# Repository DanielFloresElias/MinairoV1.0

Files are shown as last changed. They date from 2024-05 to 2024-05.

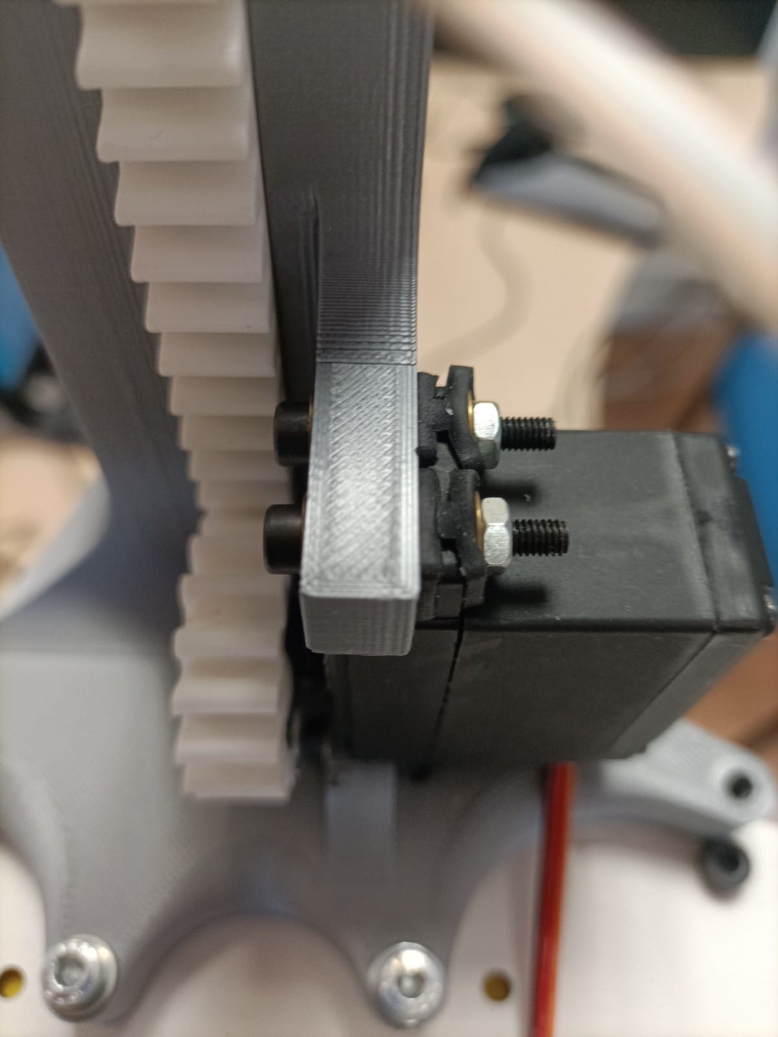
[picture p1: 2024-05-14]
Hardware/STLs/Llapis/IMG/img_pen04.jpeg

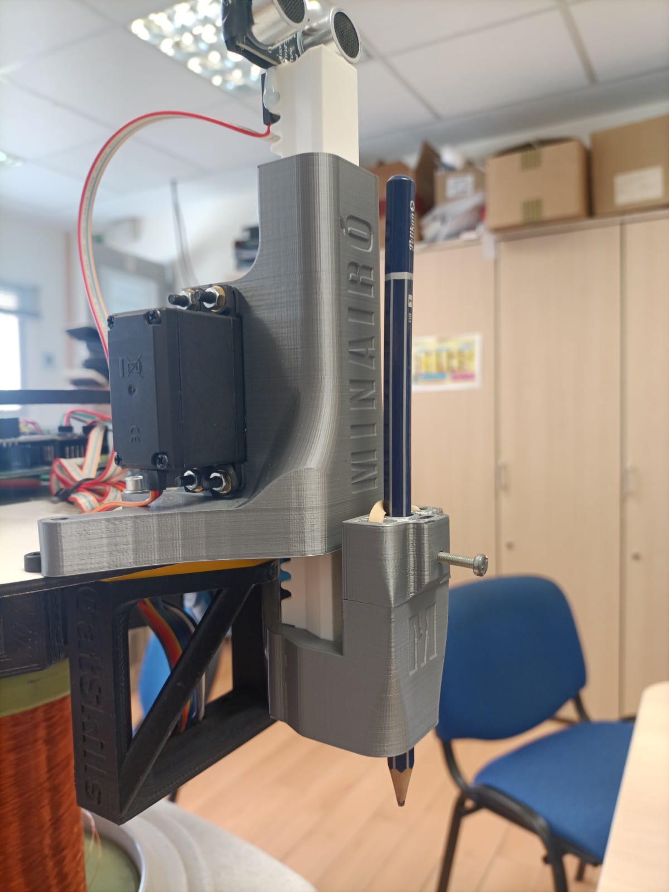
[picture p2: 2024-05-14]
Hardware/STLs/Llapis/IMG/img_pen06.jpeg

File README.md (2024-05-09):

<!--![](IMG/Minairó_Front_transp.png)-->
# MINAIRÓ V1.0 Robot
El robot Minairó es un proyecto *opensource* de robot didáctico, diseñado para aprender a programar de una manera divertida, proporcionando una plataforma *hardware* capaz de intreractuar mediante sensores y actuadores electrónicos.

Para manejar al MINAIRÓ se ha desarollado la libreria **Minairo_TCP.py**. En esta libreria encontramos los métodos necesarios para la comunicación mediante un socket TCP/IP.

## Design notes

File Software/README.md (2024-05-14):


# MINAIRÓ V1.0 Robot
El robot Minairó es un proyecto *opensource* de robot didáctico, diseñado para aprender a programar de una manera divertida, proporcionando una plataforma *hardware* capaz de intreractuar mediante sensores y actuadores electrónicos.

Para manejar al MINAIRÓ se ha desarollado la libreria **Minairo_TCP.py**. En esta libreria encontramos los métodos necesarios para la comunicación mediante un socket TCP/IP.

### Métodos para comunicaciones: [->](#item1)
```
- MinairoSocket(IP,port)
- connect():
- run():
- transmit():
- stop():
- close():
- setPullingTime(value):
- getPullingTime():
```
### Métodos para control:
```
- setVel(x,y,w):
- setX(x):
- setY(y):
- setW(w):
```
### Métodos para el seguidor de líneas:
```
- setSensorLine_Threshold(value):
- getSensorLine_Threshold():
- getSensorLine_Analog():
- getSensorLine_Digital():
```
### Método para los sensores perimetrales:
```
- getSensorSharp():
```
### Métodos para las GPIOs:
```
- confGPIO(pin,mode):
- setGPIO(pin,value):
- getGPIO():
```
### Método para entradas analógicas:
```
getAnalogs()
```
### Método para servos RC:
```
- setSERVO(pin,value):
```
### Método par SONAR:
```
- getSONAR():
```
---
---

## Métodos para comunicaciones:
### `MinairoSocket(IP,port)`
#### Descripción
Crea una instancia del Robot MINAIRÓ. En ella se incluyen todos los métodos para controlar el robot y monitorizar todos los sensores.

#### Sintaxis

```
MinairoSocket(IP,port)
```

#### Paràmetros
**IP**: Dirección IP del Robot MINAIRÓ. Por defecto 192.168.1.1.

**port**: Puerto para establecer el *socket* de comunicación. Por defecto *22*.

#### Ejemplo

```
from Minairo_TCP import *
from time import sleep

if __name__=="__main__":
    IP = '192.168.1.1'
    port = 22
    Robot = MinairoSocket(IP,port)
    Robot.run()
    Robot.setX(0.1)
    sleep(2)
    Robot.setX(0.0)
    sleep(0.5)
    Robot.close()
```
---
### `run()`
#### Descripción
El método *run()*, se conecta mediante el *socket* TCP/IP con el robot, e inicia la comunicación bidireccional ciclica entre el robot y su instancia de python.
El periodo de *polling* se establece mediante el método: *setPullingTime(value)* por defecto 25ms.

#### Sintaxis

```
run()
```

#### Paràmetros
Sin parámetros.

#### Ejemplo

```
from Minairo_TCP import *
from time import sleep

if __name__=="__main__":
    IP = '192.168.1.1'
    port = 22
    Robot = MinairoSocket(IP,port)
    Robot.run()
    Robot.setX(0.1)
    sleep(2)
    Robot.stop()
```
---
### `transmit()`
#### Descripción
El método *transmit()*, realiza una única comunicación bidireccional entre el robot y su instancia de python.En primer lugar transfiere el *OutBuffer* con todos los datos en *RAW* de control al MINAIRÓ, y seguidamente recibe el *InBuffer* con todos los datos en *RAW* procedentes de los sensores.

#### Sintaxis

```
transmit()
```

#### Paràmetros
Sin parámetros.

#### Ejemplo

```
from Minairo_TCP import *
from time import sleep

if __name__=="__main__":
    IP = '192.168.1.1'
    port = 22
    Robot = MinairoSocket(IP,port)
    Robot.connect()
    Robot.setX(0.1)
    Robot.transmit()
    sleep(2)
    Robot.setX(0.0)
    Robot.transmit()
    Robot.close()
```

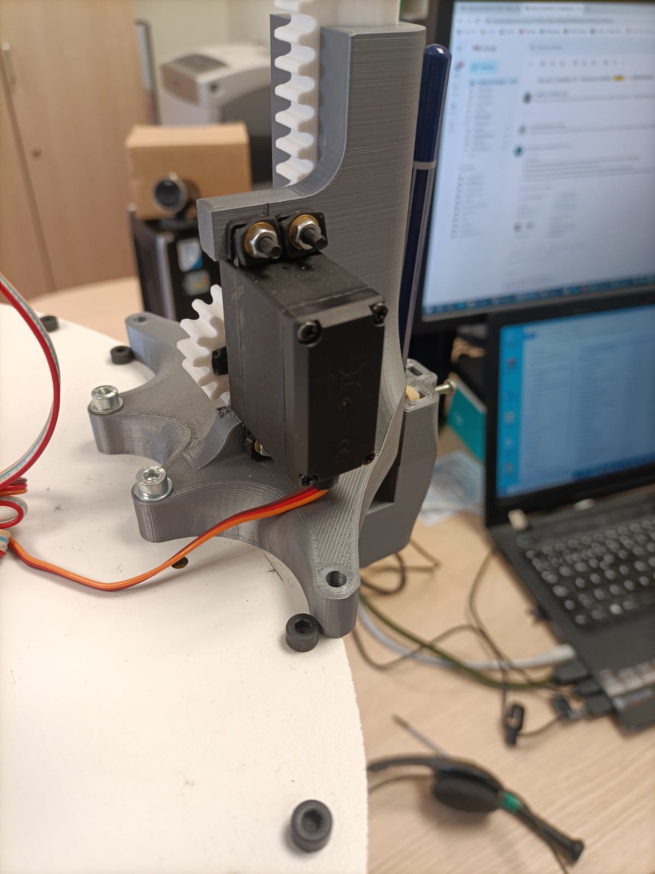
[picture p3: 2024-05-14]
Hardware/STLs/Llapis/IMG/img_pen05.jpeg

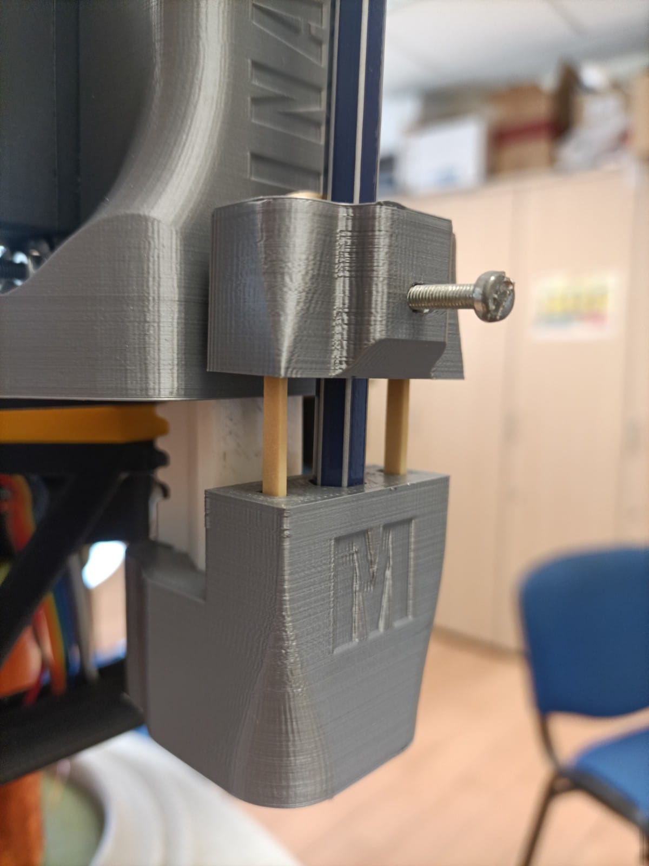
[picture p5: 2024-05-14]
Hardware/STLs/Llapis/IMG/img_pen02.jpeg

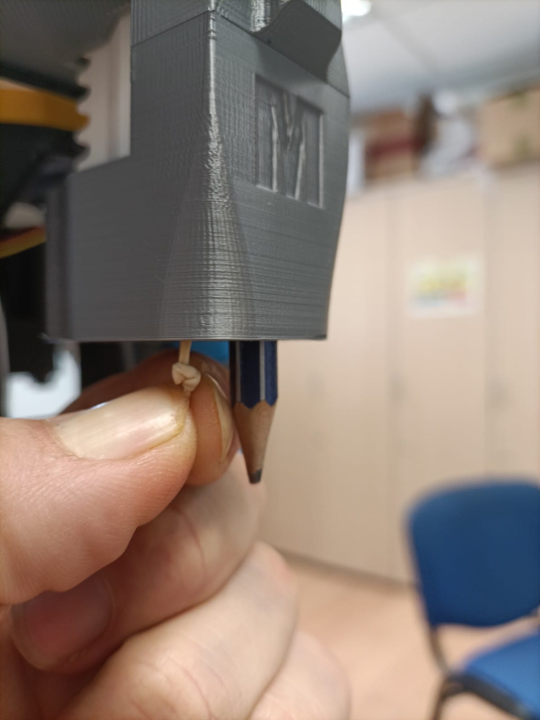
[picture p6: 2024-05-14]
Hardware/STLs/Llapis/IMG/img_pen01.jpeg

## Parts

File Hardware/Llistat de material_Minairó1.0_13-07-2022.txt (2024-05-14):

					        █╗
					       █╔╝
					       ╚╝
███╗   ███╗██╗███╗   ██╗ █████╗ ██╗██████╗  ██████╗      ██╗    ██████╗ 
████╗ ████║██║████╗  ██║██╔══██╗██║██╔══██╗██╔═══██╗    ███║   ██╔═████╗
██╔████╔██║██║██╔██╗ ██║███████║██║██████╔╝██║   ██║    ╚██║   ██║██╔██║
██║╚██╔╝██║██║██║╚██╗██║██╔══██║██║██╔══██╗██║   ██║     ██║   ████╔╝██║
██║ ╚═╝ ██║██║██║ ╚████║██║  ██║██║██║  ██║╚██████╔╝     ██║██╗╚██████╔╝
╚═╝     ╚═╝╚═╝╚═╝  ╚═══╝╚═╝  ╚═╝╚═╝╚═╝  ╚═╝ ╚═════╝      ╚═╝╚═╝ ╚═════╝ 
        __  ___   ___      ___                          ___               __        ___ ___                         __  
| |\ | /__`  |  |  |  |  |  |        |  /\  |  |  |\/| |__     |__| |  | / _` |  | |__   |     \  /  /\  |    |    /__` 
| | \| .__/  |  |  |  \__/  |     \__/ /~~\ \__/  |  | |___    |  | \__/ \__> \__/ |___  |      \/  /~~\ |___ |___ .__/ 
                                                                                                                                                                                              

1x Roda ominidreccional:
	Impressió PLA:
		- 2x "BaseRoda80mm.stl"
		- 2x "BaseRoda80mm_B.stl"
	Impressió TPU:
		- 6x "Rodillo80mm_coixinet11mm.stl"
	Ferreteria:
		- 12x Tornillo Hallen M3 16mm
		- 9x Tuerca M3
		- 6x Barilla roscada M5 49mm
		- 12x Arandela M5
		- 12x cojinete MR115-2RS (11x5x4)
		- 1x  eje 6 mm / M3 de Pololu 1999 (https://www.pololu.com/product/1999)
Electrico:
	MUCHOS DE ESTOS COMPONENTES SE PUEDEN ADQUIRIR EN WWW.BRICOGEEK.COM
	- 3x Motor:  Motor con reductora 70:1 con encoder de Pololu 4754 (https://www.pololu.com/product/4754)
	- 2x Driver Motor: Dual VNH5019 Motor Driver Shield for Arduino (https://www.pololu.com/product/2507)
	- 3x Arduino Nano Every de Arduino ABX00028
	- 1x Regulador DC-DC 12-24V a 5V (5A) de BricoGeek (https://tienda.bricogeek.com/convertidores-de-voltaje/1650-regulador-dc-dc-12-24v-a-5v-5a.html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)
	- 1x Conector XT60 batería.
	- 2x Bateria tipo CONGA 14,4V Li-Ion
	- 4x Sensor de distancia 2-15cm - Sharp GP2Y0A51SK0F de Pololu 2450 (2-150mm) / Sensor de proximidad Sharp GP2Y0A21YK de Pololu 136 (100-800mm)
	- 1x Array de sensores infrarrojos QTR-8RC (Digital) (https://www.pololu.com/product/961)
	- 1x ESP32 Wroom WIFI + Bluetooth (https://tienda.bricogeek.com/arduino-compatibles/1274-esp32-wroom-wifi-bluetooth.html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)
	- 1x 4 Channel IIC I2C Logic Level Converter Bi-Directional Module 5V to 3.3V For Arduino (https://www.amazon.es/dp/B06Y5KKMLL?psc=1&ref=ppx_yo2ov_dt_b_product_details)

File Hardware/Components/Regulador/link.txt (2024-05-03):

https://tienda.bricogeek.com/convertidores-de-voltaje/1650-regulador-dc-dc-12-24v-a-5v-5a.html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

Características:

Voltaje de entrada: 12 a 24V
Voltaje de salida: 5V
Corriente de salida: 5A max
Eficiencia: 90%
Ripple: 150mA (p-p)
Corriente sin carga: 15mA
Protección con sobre corriente y sobre voltaje.
Dimensiones: 63x32x18mm
Peso: 65 gramos

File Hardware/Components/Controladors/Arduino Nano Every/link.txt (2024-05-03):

https://docs.arduino.cc/hardware/nano-every

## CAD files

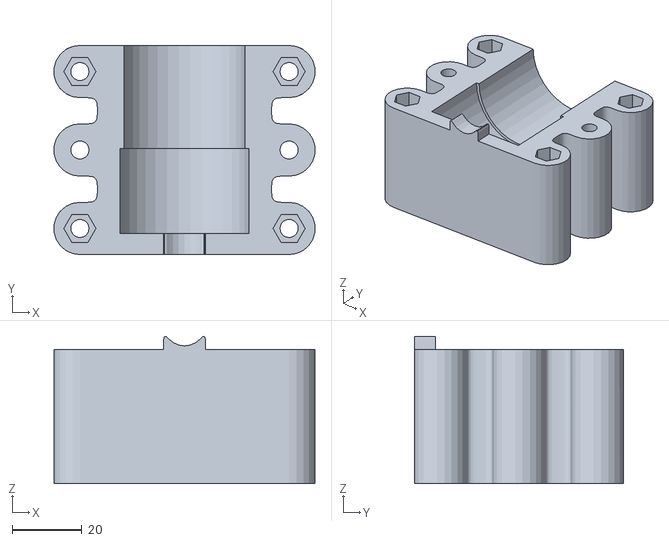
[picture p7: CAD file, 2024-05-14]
Hardware/STLs/Base_Robot/Suport_B.stl
74.8 x 60.0 x 42.2

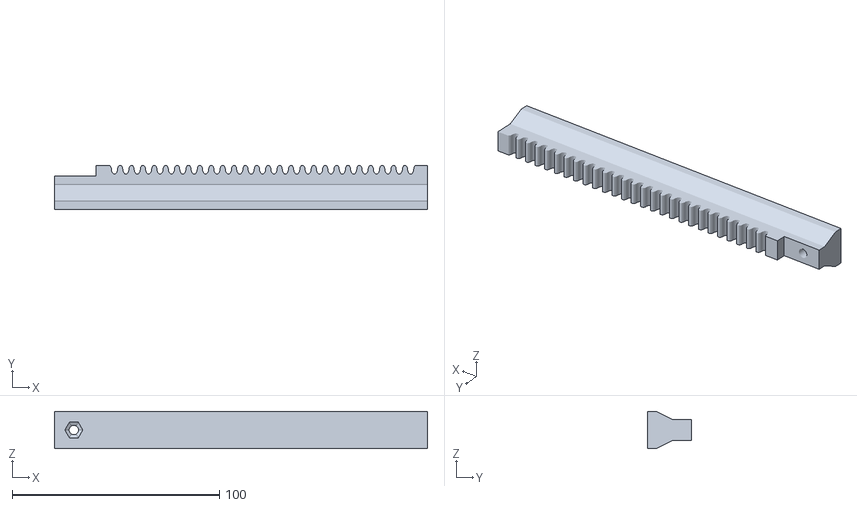
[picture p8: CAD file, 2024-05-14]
Hardware/STLs/Llapis/Corredera.STL
180.0 x 21.0 x 18.0

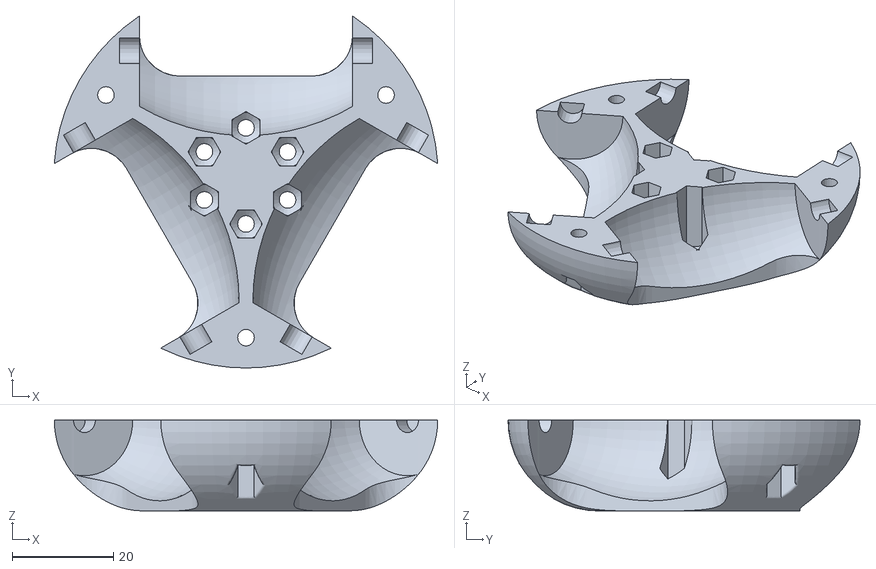
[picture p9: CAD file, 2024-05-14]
Hardware/STLs/Rodes/BaseRoda80mm_B.stl
75.8 x 69.6 x 18.0

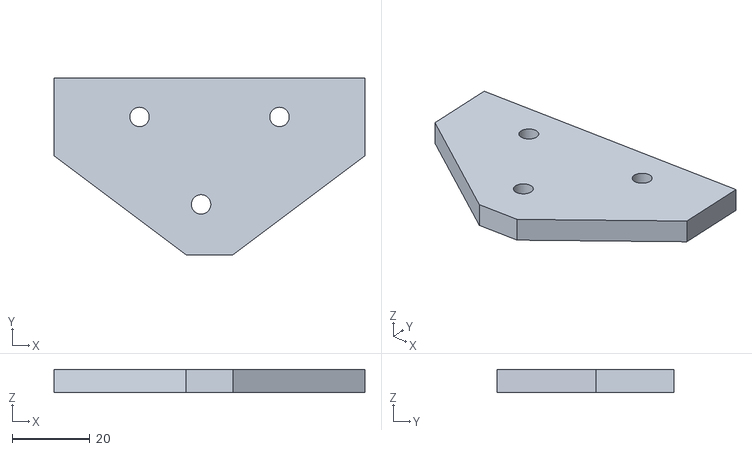
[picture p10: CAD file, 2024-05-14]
Hardware/STLs/Suport Sensors/SuportSensorArray_GAP.STL
80.0 x 45.5 x 6.00

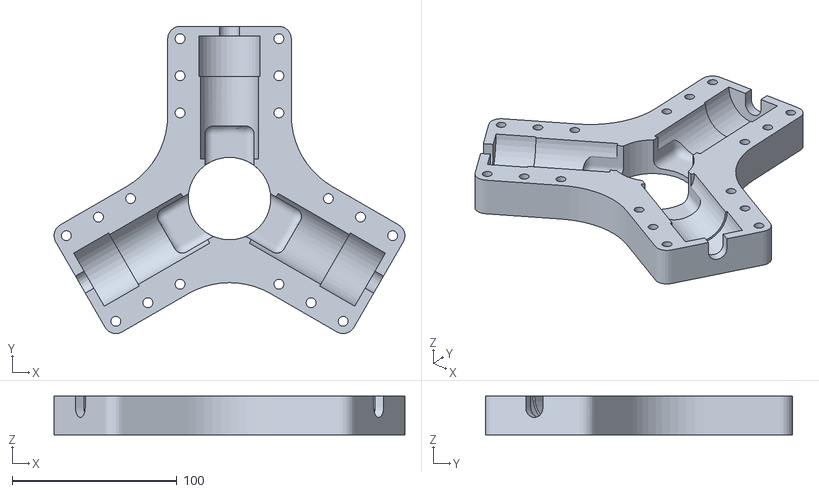
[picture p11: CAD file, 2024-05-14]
Hardware/STLs/Base_Robot/BaseRobot_BottomSide_V2.stl
212.9 x 186.4 x 23.5

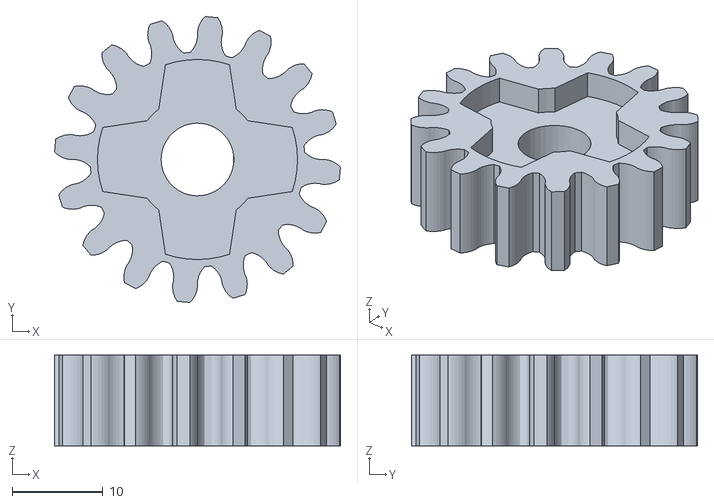
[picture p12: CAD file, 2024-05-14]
Hardware/STLs/Llapis/Engranatge.STL
31.5 x 31.5 x 10.0

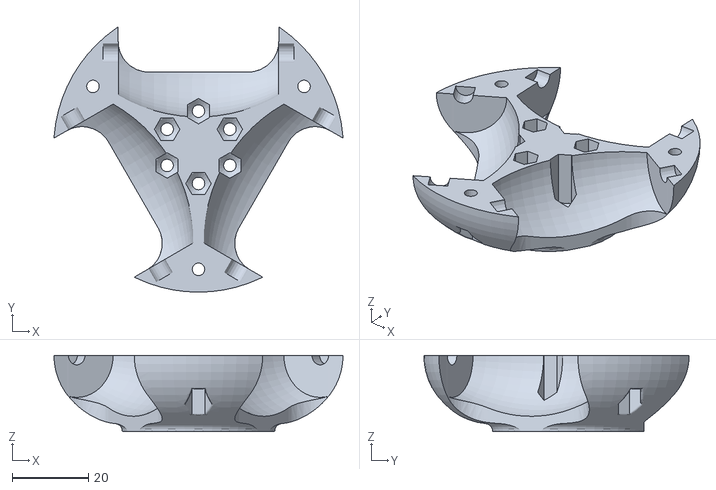
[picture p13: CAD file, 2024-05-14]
Hardware/STLs/Rodes/BaseRoda80mm.stl
75.8 x 69.6 x 20.0

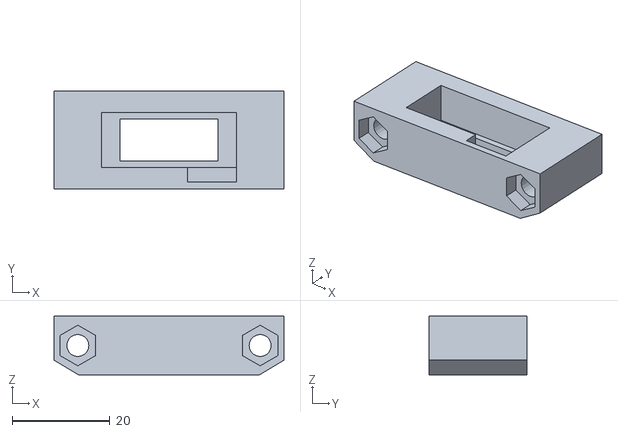
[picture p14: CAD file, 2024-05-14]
Hardware/STLs/Suport Sensors/SuportSensorOptic.stl
47.0 x 20.0 x 12.0

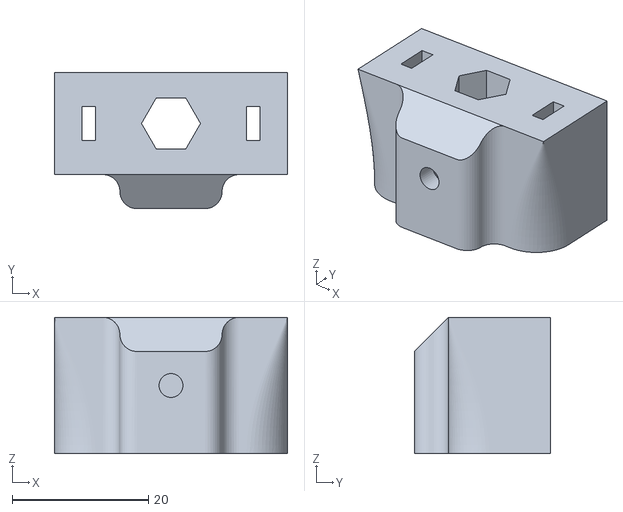
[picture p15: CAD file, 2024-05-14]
Hardware/STLs/Llapis/SuportLlapisB.STL
34.2 x 20.0 x 20.0

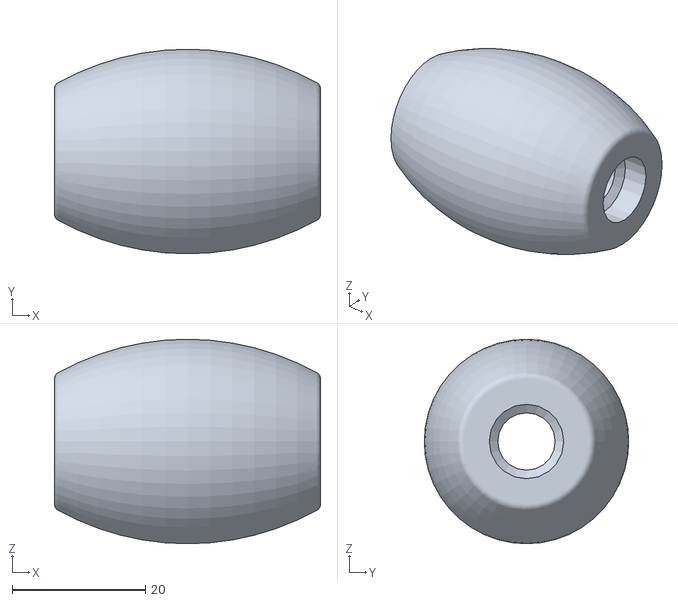
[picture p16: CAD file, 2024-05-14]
Hardware/STLs/Rodes/Rodillo80mm_coixinet11mm.stl
40.0 x 30.8 x 30.8

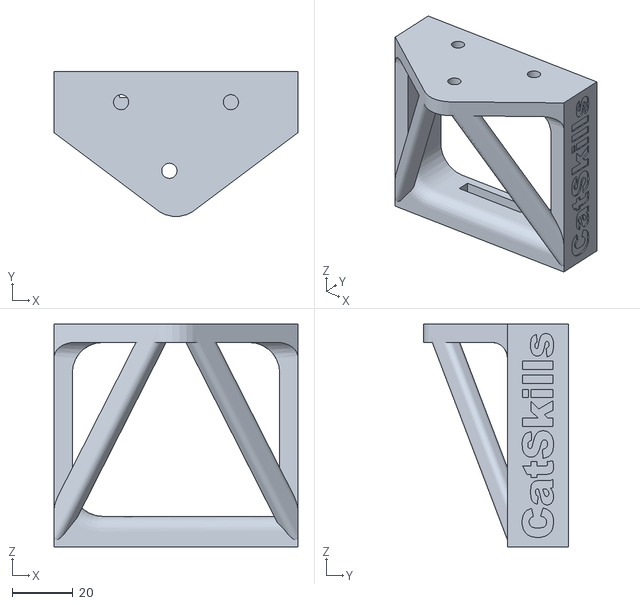
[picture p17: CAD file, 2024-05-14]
Hardware/STLs/Suport Sensors/SuportSensorArray.stl
80.0 x 47.4 x 73.0

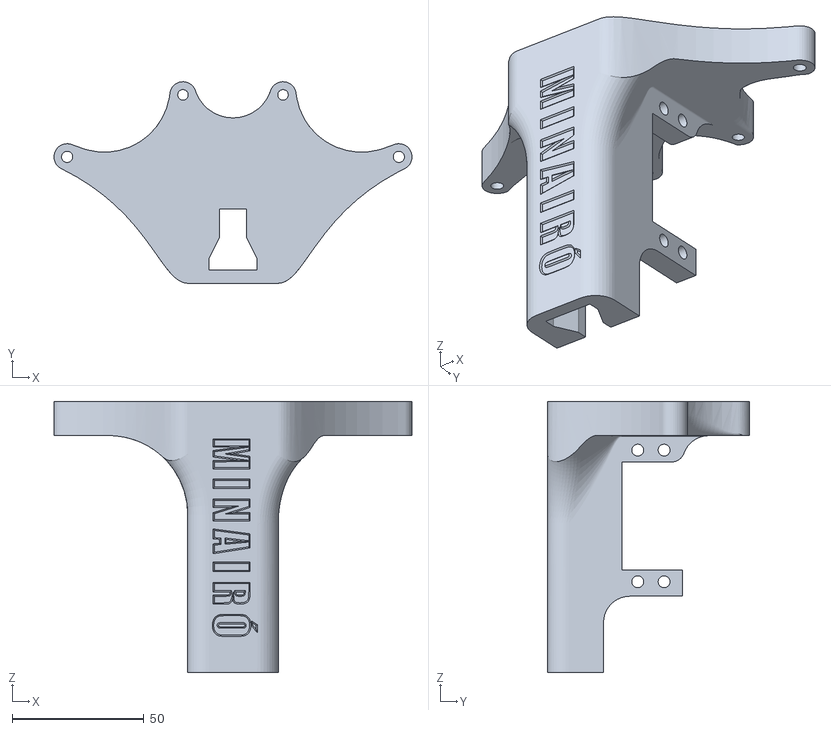
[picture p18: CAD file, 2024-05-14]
Hardware/STLs/Llapis/BaseCorredera.STL
136.0 x 76.6 x 103.0

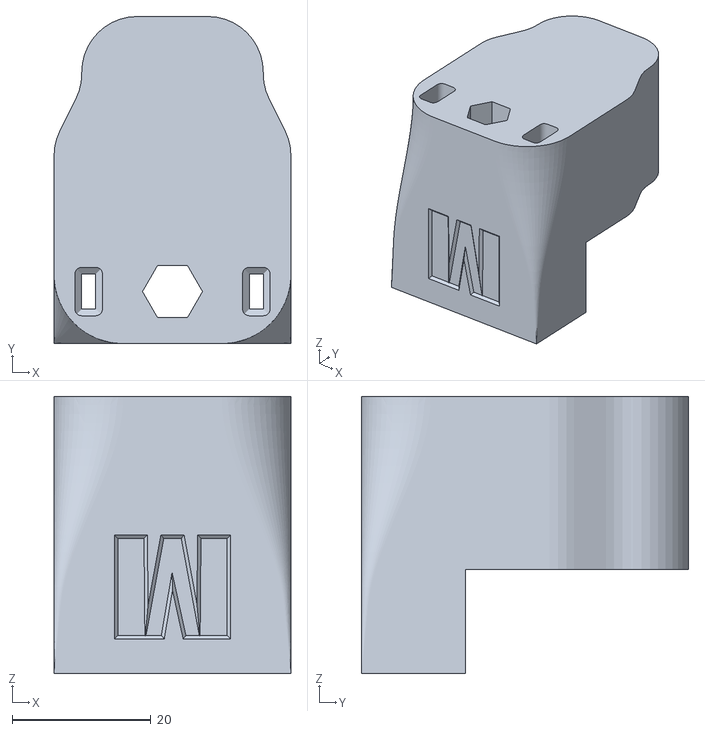
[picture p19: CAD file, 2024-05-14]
Hardware/STLs/Llapis/SuportLlapis.STL
34.2 x 47.2 x 40.0

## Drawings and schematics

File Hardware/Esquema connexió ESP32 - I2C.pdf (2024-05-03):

## MASTER

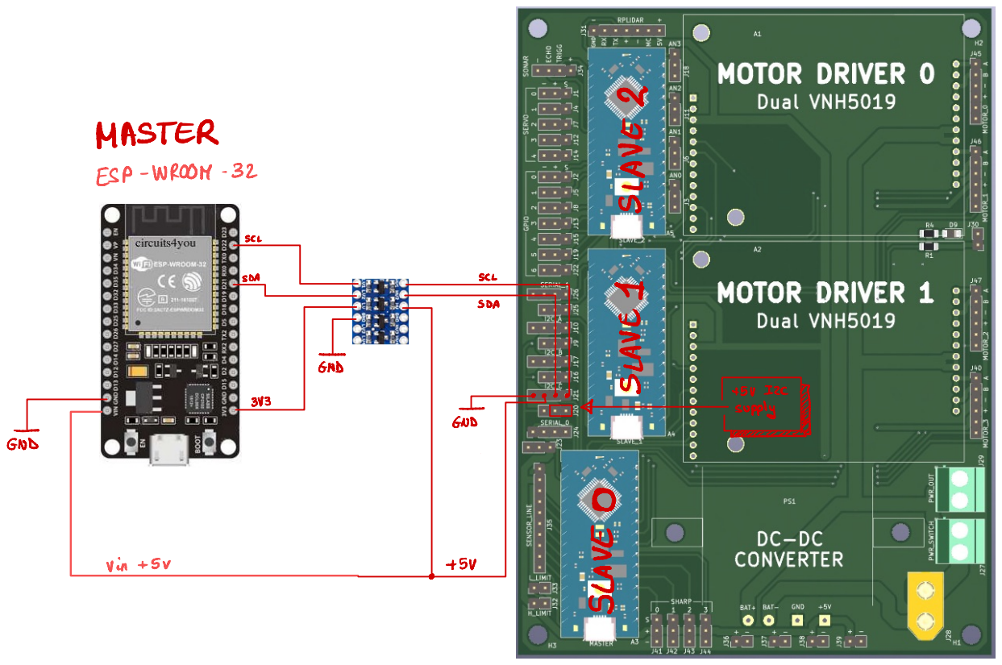
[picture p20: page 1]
ESP-WROOM-32; SDA; SCL; - SCL; goopacT; GND; vin + sv

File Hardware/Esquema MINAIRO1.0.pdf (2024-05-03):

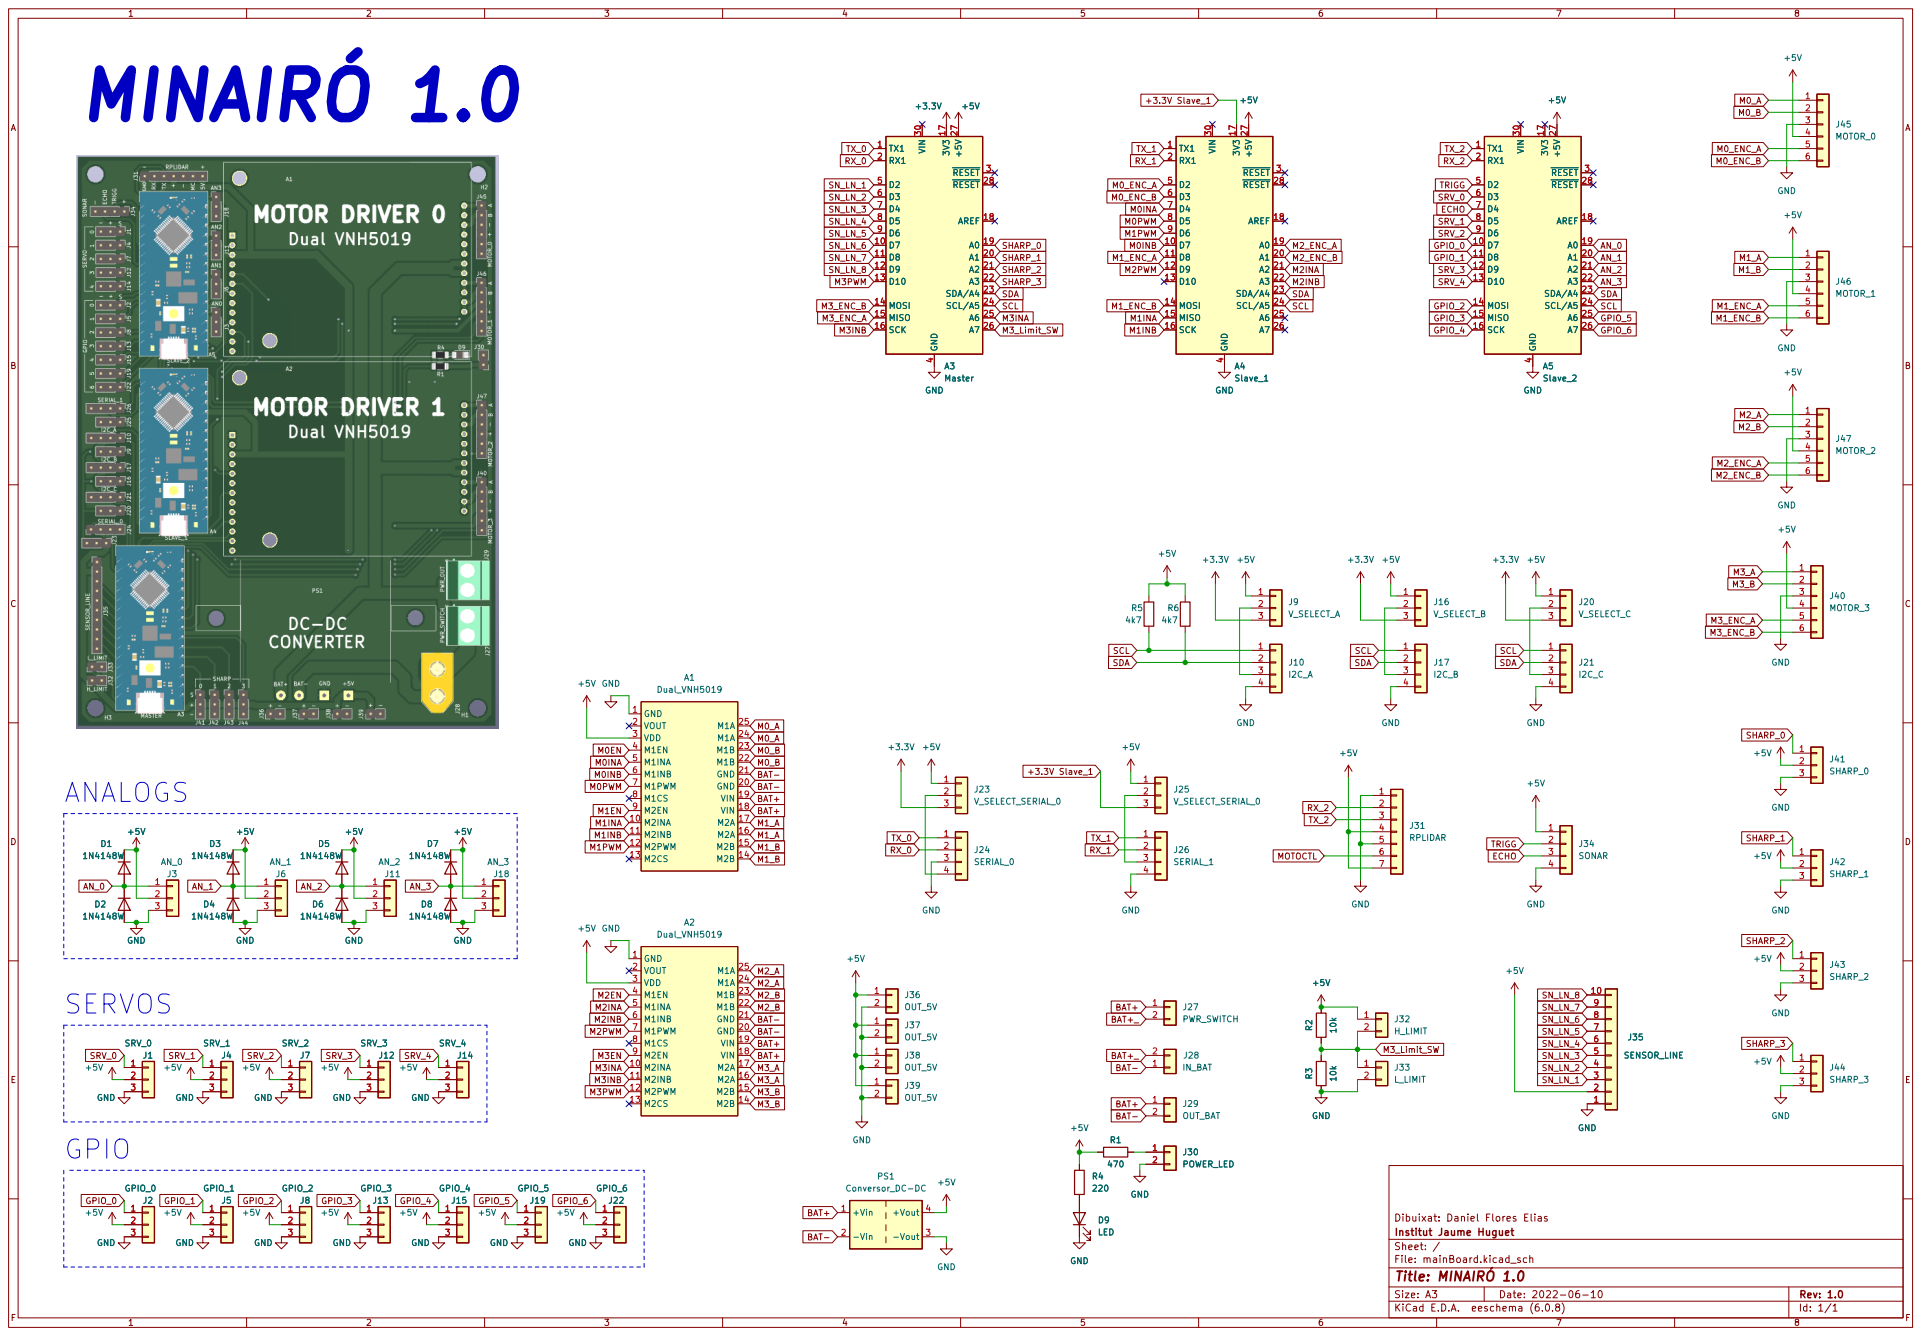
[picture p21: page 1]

Institut Jaume Huguet Dibuixat: Daniel Flores Elias GND

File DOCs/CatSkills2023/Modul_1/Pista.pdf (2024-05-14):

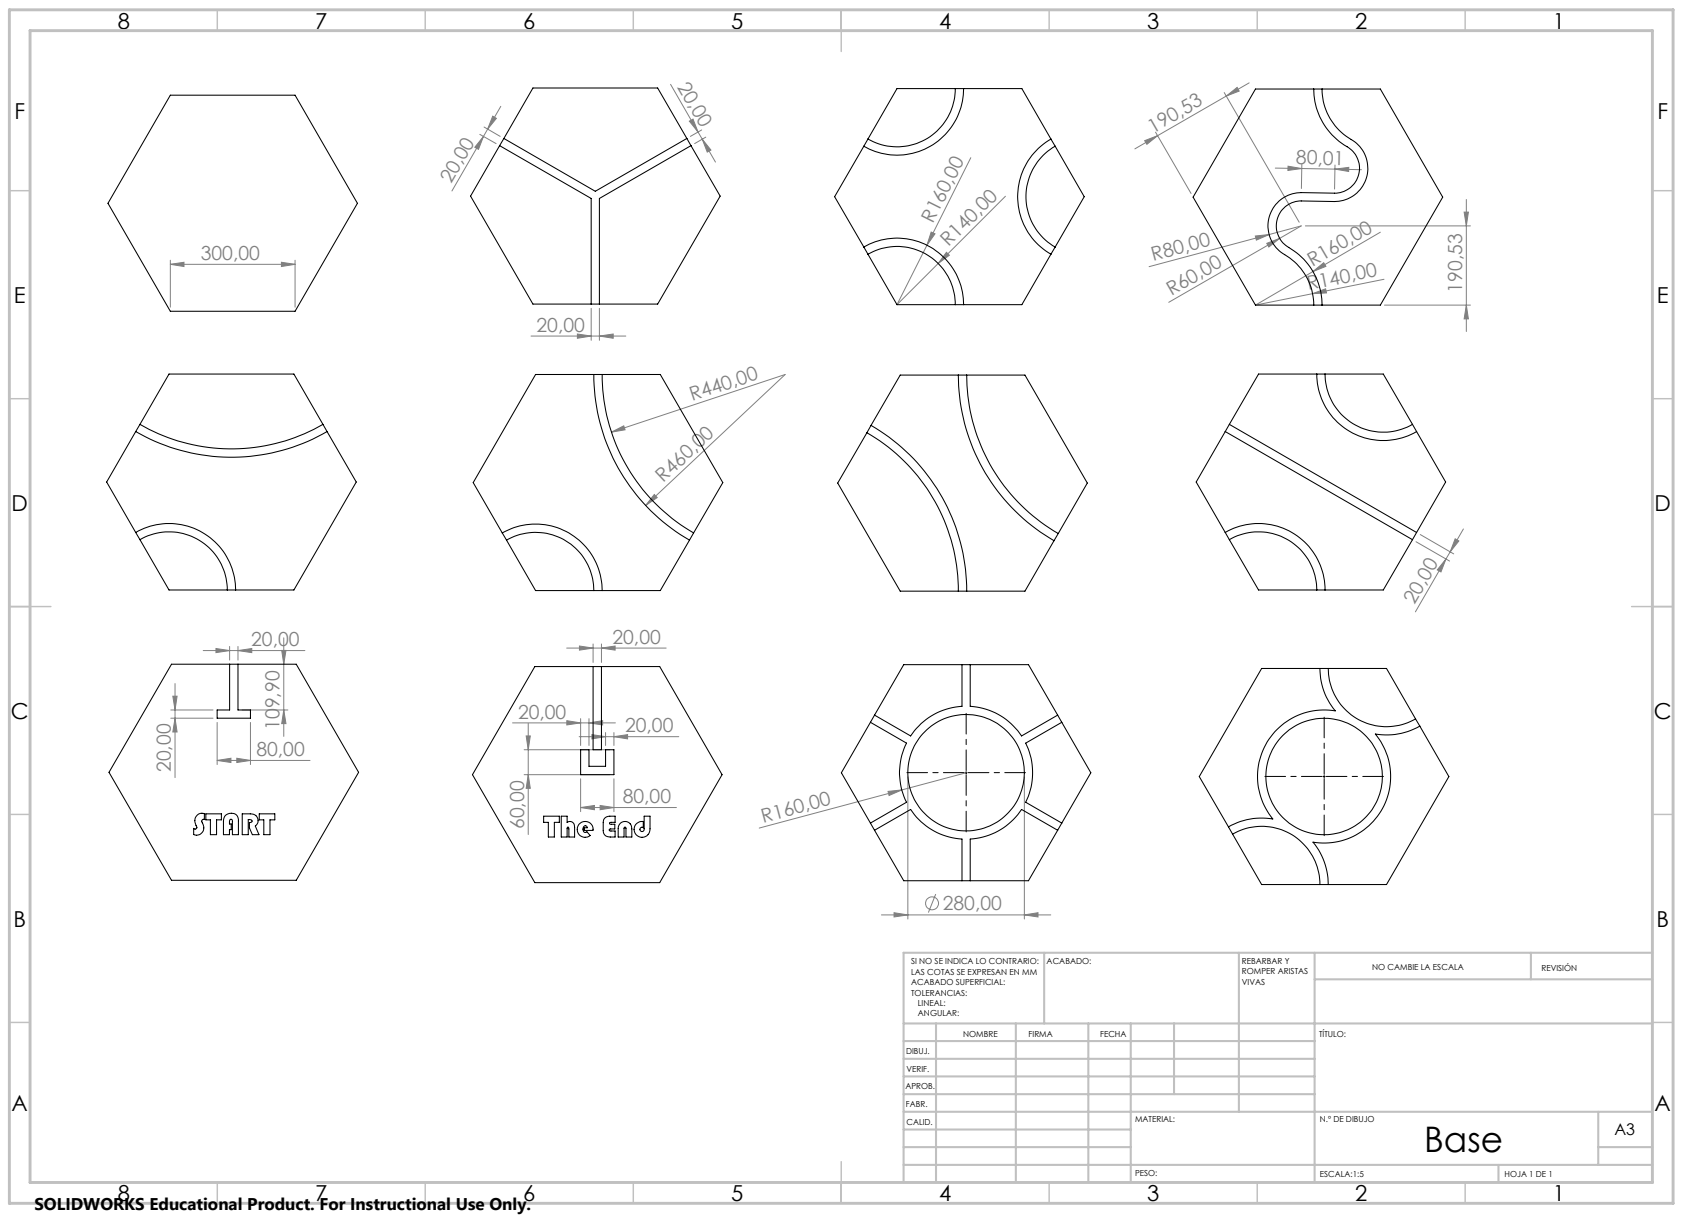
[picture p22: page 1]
ACABADO:; REBARBAR Y; ROMPER ARISTAS; NO CAMBIE LA ESCALA; REVISIÓN; ESCALA:1:5; HOJA 1 DE 1

SI NO SE INDICA LO CONTRARIO:
LAS COTAS SE EXPRESAN EN MM
ACABADO SUPERFICIAL:
TOLERANCIAS:
LINEAL:
ANGULAR:

NOMBRE | FIRMA | FECHA | | | | TÍTULO:

DIBUJ.
VERIF.
APROB.
FABR.
CALID. | | | | MATERIAL: | N.º DE DIBUJO Base | A3

SOLIDWORKS Educational Product. For Instructional Use Only.

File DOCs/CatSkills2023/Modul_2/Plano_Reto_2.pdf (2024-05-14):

E E

F F

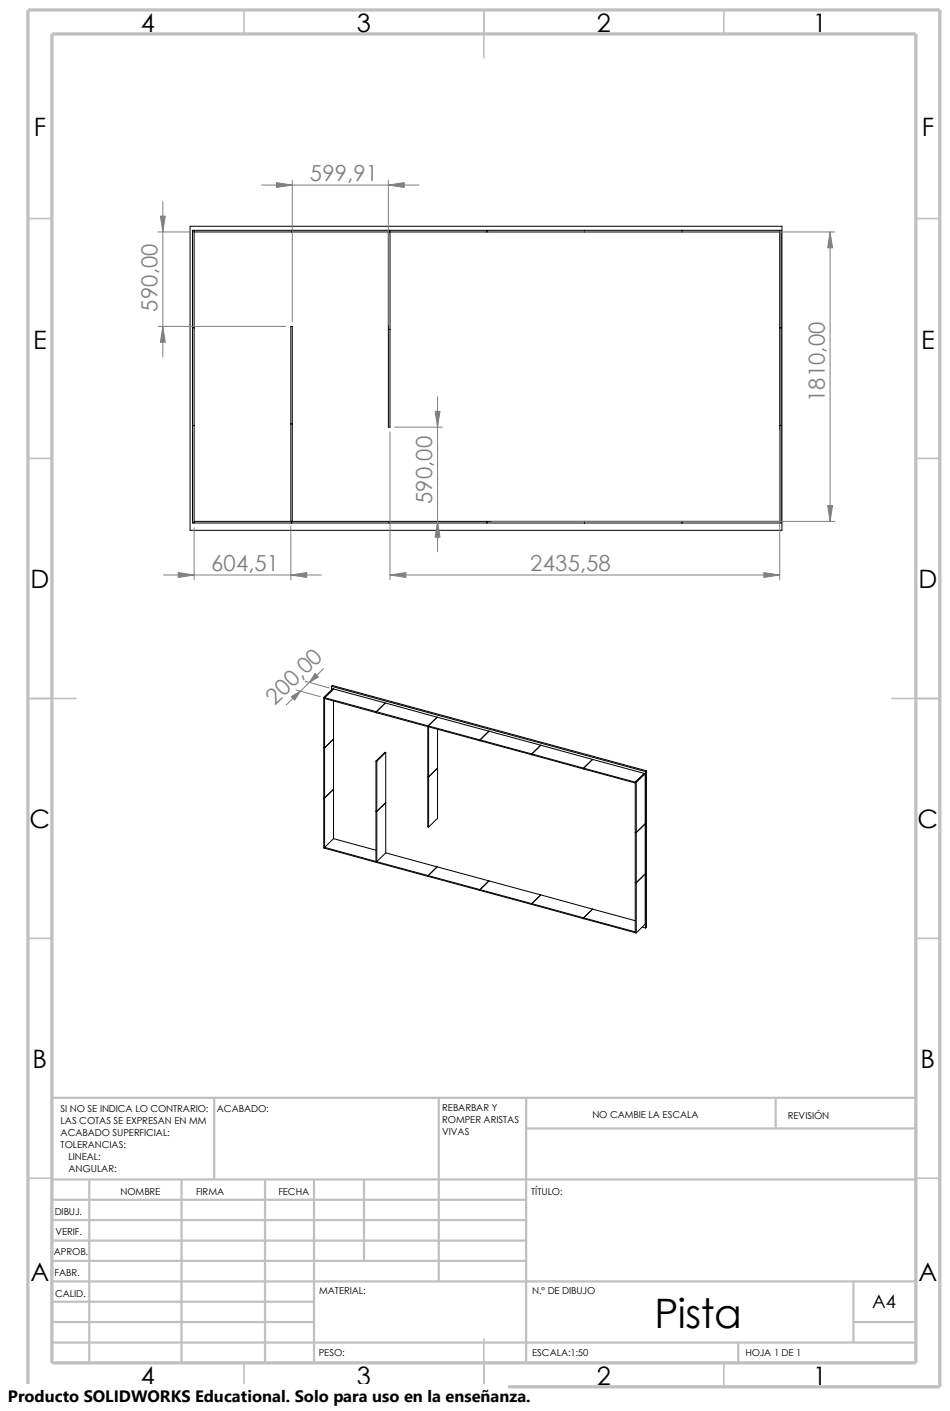
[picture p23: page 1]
ESCALA:1:50; HOJA 1 DE 1; PESO:; N.º DE DIBUJO; NO CAMBIE LA ESCALA; REVISIÓN; MATERIAL:; FABR.; CALID.; ACABADO:; VIVAS; REBARBAR Y ROMPER ARISTAS; Pista

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

NOMBRE | FIRMA | FECHA | TÍTULO:

DIBUJ.
VERIF.
APROB.

Producto SOLIDWORKS Educational. Solo para uso en la enseñanza.

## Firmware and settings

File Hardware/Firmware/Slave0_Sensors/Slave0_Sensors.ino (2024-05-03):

/*
    __  __ _             _        _    __   ___
   |  \/  (_)           (_)      //   /_ | / _ \
   | \  / |_ _ __   __ _ _ _ __ ___    | || | | |
   | |\/| | | '_ \ / _` | | '__/ _ \   | || | | |
   | |  | | | | | | (_| | | | | (_) |  | || |_| |
   |_|  |_|_|_| |_|\__,_|_|_|  \___/   |_(_)___/

   Descripción: Este firmware, gestiona las comunicaciones entre el Robot Minairó i la UART.
   El Master, gestiona los comandos entrantes. Atiende los comandos locales, i redirecciona los
   comandos a los Slaves correspondientes.

   Funciones del M0aster:
      - Control del motor auxiliar (MOTOR_3) Con control de posición.
      - 2x Finales de carrera MOTOR_3
      - 8x Sensores del seguidor de Línea
      - 4x Sensores Analógicos perimetrales
      - Comunicación UART con periferia
      - Comunicación I2C con Slaves.

   Versión: 1.0
   Autor: Daniel Flores Elias
   mail: daniel.flores@gmail.com

   Copyright (c) 2023 Institut Jaume Huguet-Valls, Daniel Flores
   <daniel.flores@gmail.com>  All rights reserved.
   See the bottom of this file for the license terms.

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
   1. Redistributions of source code must retain the above copyright
   notice, this list of conditions and the following disclaimer.

   2. Redistributions in binary form must reproduce the above copyright
   notice, this list of conditions and the following disclaimer in the
   documentation and/or other materials provided with the distribution.

   3. Neither the name of the copyright holder nor the names of its
   contributors may be used to endorse or promote products derived from
   this software without specific prior written permission.

   THIS SOFTWARE IS PROVIDED BY THE COPYRIGHT HOLDERS AND CONTRIBUTORS
   "AS IS" AND ANY EXPRESS OR IMPLIED WARRANTIES, INCLUDING, BUT NOT
   LIMITED TO, THE IMPLIED WARRANTIES OF MERCHANTABILITY AND FITNESS FOR
   A PARTICULAR PURPOSE ARE DISCLAIMED. IN NO EVENT SHALL THE COPYRIGHT
   HOLDER OR CONTRIBUTORS BE LIABLE FOR ANY DIRECT, INDIRECT, INCIDENTAL,
   SPECIAL, EXEMPLARY, OR CONSEQUENTIAL DAMAGES (INCLUDING, BUT NOT
   LIMITED TO, PROCUREMENT OF SUBSTITUTE GOODS OR SERVICES; LOSS OF USE,
   DATA, OR PROFITS; OR BUSINESS INTERRUPTION) HOWEVER CAUSED AND ON ANY
   THEORY OF LIABILITY, WHETHER IN CONTRACT, STRICT LIABILITY, OR TORT
   (INCLUDING NEGLIGENCE OR OTHERWISE) ARISING IN ANY WAY OUT OF THE USE
   OF THIS SOFTWARE, EVEN IF ADVISED OF THE POSSIBILITY OF SUCH DAMAGE.
*/

#include "Encoder.h"
#include "AccelMotor.h"
#include <EEPROM.h>
#include <QTRSensors.h>
#include <Wire.h>
#include "COMParameters.h"


int eeAddress = 0;
int SALVE_0_ADDR = 8;

_SLAVE0_IN  Slave_0_IN;
_SLAVE0_OUT Slave_0_OUT;

Encoder myEnc(11, 12);
//   avoid using pins with LEDs attached
AccelMotor motor(DRIVER3WIRE, 13, 20, 10, HIGH);

QTRSensors qtr;
const uint8_t SensorCount = 8;
uint16_t sensorValues[SensorCount];

const float Rad2Ticks = 4480 / (2 * PI);


float Teta = 0;
float Dist = 0;
float DistTotal = 0;
float Radi = 1; // Radi de la Roda en metres
float Speed = 0;
unsigned long TempsOld = 0;
uint8_t tempsPulling = 20;
const float tempsCalc = float(tempsPulling) / 1000.0;

String InString = "";
String OutString = "";
String Comando = "";
bool NewLine = false;
String Temporal = "";

bool  Transmit = false;
bool  TimeOut = false;
int TempsTimeOut = 200;
unsigned long TempsOld_TimeOut = 0;

int TransmitTime = 100;
unsigned long TempsOld_TransmitTime = 0;

long oldPosition  = 0;

int H_LimitSwitch = 0;
bool H_LimitSwitchOld = 0;
int L_LimitSwitch = 0;
bool L_LimitSwitchOld = 0;

bool MotorHomeFlag = false;
bool DataReceived = false;

const int Sensors = 4;
const int Mostres = 8;
int SensorArray[ Sensors ][ Mostres ];
uint16_t TempSharpArray[Sensors];




void setup() {
  Slave_0_IN.INPUT_DATA.CtrlWord1 = 0;
  Slave_0_IN.INPUT_DATA.CtrlWord2 = 0;
  Slave_0_IN.INPUT_DATA.SetPoint = 0;
  Wire.setClock( 400000L);
  Wire.begin(SALVE_0_ADDR);
  Serial.begin(115200);
  Wire.onRequest(RequestEven); // registrar evento de solicitud de datos
  Wire.onReceive(receiveEvent); // registrar evento de recepcion de datos

  // Yo uso el motor
  // codificador 64 tics por revolución
  motor.setRatio(70 * 64);
  // período de integración (por defecto 20)
  motor.setDt(20);  // milisegundos
  // configuración de la velocidad máxima para el modo ACCEL_POS
  motor.setMaxSpeedDeg(300);  // en grados / seg
  // configuración de la aceleración para el modo ACCEL_POS
  motor.setAccelerationDeg(5);  // en grados / seg / seg
  // señal PWM mínima (módulo) (en la que el motor arranca)
  motor.setMinDuty(10);
  // Coeficientes del regulador PID
  motor.kp = 0.5;   // responsable de la nitidez de la regulación.
  // A valores bajos, no habrá señal en absoluto, a valores demasiado altos, temblará
  motor.ki = 0.0; // responsable de corregir el error a lo largo del tiempo
  motor.kd = 0.0; // responsable de compensar los cambios repentinos
  // establecer la zona de parada del motor para el modo de estabilización de posición en ticks (por defecto 8)
  motor.setStopZone(100);
  motor.setRunMode(PID_POS);

  // configure the sensors
  qtr.setTypeRC();
  qtr.setSensorPins((const uint8_t[]) {
    2, 3, 4, 5, 6, 7, 8, 9
  }, SensorCount);
  qtr.calibrate();

  for (uint8_t i = 0; i < SensorCount; i++)
  {
    qtr.calibrationOn.minimum[i] = 500;
    qtr.calibrationOn.maximum[i] = 2500;
  }

}

void loop() {
  //////////// P U L L I N G //////////////
  if (millis() > (TempsOld + tempsPulling)) {
    TempsOld += tempsPulling;
    Slave_0_OUT.OUTPUT_DATA.EncoderValue = myEnc.read();

    if (!(Slave_0_IN.INPUT_DATA.CtrlWord1 & MotorHomeMask)) {
      MotorHomeFlag = false;
      motor.setTarget(Slave_0_IN.INPUT_DATA.SetPoint);
    }

    if ((Slave_0_IN.INPUT_DATA.CtrlWord1 & MotorHomeMask) && !MotorHomeFlag) {
      MotorHomeFlag = true;
      Slave_0_IN.INPUT_DATA.SetPoint = 0;
      myEnc.write(0);
      motor.setTarget(0);
    }

    ////////////// Control de Finales de carrera del motor auxiliar //////////////
    Slave_0_OUT.OUTPUT_DATA.StatusWord1 = (analogRead(A7) > 768) ? Slave_0_OUT.OUTPUT_DATA.StatusWord1 | MotorHswMask : Slave_0_OUT.OUTPUT_DATA.StatusWord1 & ~MotorHswMask ;
    Slave_0_OUT.OUTPUT_DATA.StatusWord1 = (analogRead(A7) < 256) ? Slave_0_OUT.OUTPUT_DATA.StatusWord1 | MotorLswMask : Slave_0_OUT.OUTPUT_DATA.StatusWord1 & ~MotorLswMask ;

    ////////////// Forzado del Final de carrera HIGH //////////////
    if ((Slave_0_OUT.OUTPUT_DATA.StatusWord1 & MotorHswMask) && !H_LimitSwitchOld)
    {
      Slave_0_IN.INPUT_DATA.SetPoint = Slave_0_OUT.OUTPUT_DATA.EncoderValue;
    }
    ////////////// Forzado del Final de carrera LOW //////////////
    if ((Slave_0_OUT.OUTPUT_DATA.StatusWord1 & MotorLswMask) && !L_LimitSwitchOld)
    {
      Slave_0_IN.INPUT_DATA.SetPoint = Slave_0_OUT.OUTPUT_DATA.EncoderValue;
    }
    H_LimitSwitchOld = (Slave_0_OUT.OUTPUT_DATA.StatusWord1 & MotorHswMask) ? true : false;
    L_LimitSwitchOld = (Slave_0_OUT.OUTPUT_DATA.StatusWord1 & MotorLswMask) ? true : false;

    //motor.setMaxSpeedDeg(xxxx);  // en grados / seg


    ///////////// Actualización sensores de seguidor de línea /////////////
    qtr.read(sensorValues);
    Slave_0_OUT.OUTPUT_DATA.LS_0 = sensorValues[0];
    Slave_0_OUT.OUTPUT_DATA.LS_1 = sensorValues[1];
    Slave_0_OUT.OUTPUT_DATA.LS_2 = sensorValues[2];
    Slave_0_OUT.OUTPUT_DATA.LS_3 = sensorValues[3];
    Slave_0_OUT.OUTPUT_DATA.LS_4 = sensorValues[4];
    Slave_0_OUT.OUTPUT_DATA.LS_5 = sensorValues[5];
    Slave_0_OUT.OUTPUT_DATA.LS_6 = sensorValues[6];
    Slave_0_OUT.OUTPUT_DATA.LS_7 = sensorValues[7];

    ///////////// Actualización sensores perimetrales /////////////
    for (int i = (Mostres - 1); i > 0; i--) {
      for (int j = 0; j < Sensors; j++) {
        SensorArray[ j ][ i ] = SensorArray[ j ][i - 1];
      }
    }
    SensorArray[ 0 ][ 0 ] = analogRead(A0);
    SensorArray[ 1 ][ 0 ] = analogRead(A1);
    SensorArray[ 2 ][ 0 ] = analogRead(A2);
    SensorArray[ 3 ][ 0 ] = analogRead(A3);
    
    for(int j = 0; j<Sensors ;j++){
      TempSharpArray[j] = 0;
      for(int i = 0; i < Mostres; i++){
        TempSharpArray[j] = TempSharpArray[j] + SensorArray[j][i];
      }
      TempSharpArray[j] = TempSharpArray[j] >> 3;
    }

    Slave_0_OUT.OUTPUT_DATA.SS_0 = TempSharpArray[0];
    Slave_0_OUT.OUTPUT_DATA.SS_1 = TempSharpArray[1];
    Slave_0_OUT.OUTPUT_DATA.SS_2 = TempSharpArray[2];
    Slave_0_OUT.OUTPUT_DATA.SS_3 = TempSharpArray[3];;

  } ///______________ FINAL DEL PULLING ______________

  ////////////   C O M U N I C A C I O N E S  ////////////
  if (DataReceived) {
    TempsOld_TimeOut = millis();
    DataReceived = false; // Reinicia el valor de DataReceived

  }///______________ FINAL DE COMUNICACIONES ______________


  // función requerida. Hace todos los cálculos
  // toma el valor actual de un codificador o potenciómetro
  motor.tick(myEnc.read());
}


//***************** F U N C T I O N S *****************

// Función requerida al recibir datos por I2C
void receiveEvent(int howMany)
{
  int n = 0;
  while (Wire.available()) { // slave may send less than requested
    Slave_0_IN.B[n] = Wire.read();    // receive a byte as character
    n++;
  }
  DataReceived = true;     // nova línea.
}

// Función a ejecutar cuando Maestro solicita datos
void RequestEven() {
  for (int i = 0; i < sizeof(Slave_0_OUT); i++) {
    Wire.write(Slave_0_OUT.B[i]);
  }
}

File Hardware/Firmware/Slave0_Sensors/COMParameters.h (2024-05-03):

typedef union{
  byte B[12];
  struct{
      float x;                // m/s
      float y;                // m/s
      float w;                // rad/s
  } INPUT_DATA;
}_SLAVE1_IN;

typedef union{
  byte B[8];
  struct{
      uint16_t CtrlWord1;     // [b0]Enable, [b1]Home,
      uint16_t CtrlWord2; 
      uint32_t SetPoint;          // ticks
  } INPUT_DATA;
}_SLAVE0_IN;

#define MotorEnableMask 0x0001
#define MotorHomeMask   0x0002

typedef union{
  byte B[32];
  struct{
      uint16_t StatusWord1;     // [b0]L_SW, [b1]H_SW,
      uint16_t StatusWord2; 
      int32_t EncoderValue;          // ticks
      uint16_t LS_0;
      uint16_t LS_1;
      uint16_t LS_2;
      uint16_t LS_3;
      uint16_t LS_4;
      uint16_t LS_5;
      uint16_t LS_6;
      uint16_t LS_7;
      uint16_t SS_0;
      uint16_t SS_1;
      uint16_t SS_2;
      uint16_t SS_3;
  } OUTPUT_DATA;
}_SLAVE0_OUT;

#define MotorHswMask  0x0001
#define MotorLswMask  0x0002

typedef union{
  byte B[12];
  struct{
      uint8_t GPIO_Config;       
      uint8_t GPIO_Value;       
      uint16_t Servo_0;       // pulse width in micro seconds
      uint16_t Servo_1;       // pulse width in micro seconds
      uint16_t Servo_2;       // pulse width in micro seconds
      uint16_t Servo_3;       // pulse width in micro seconds
      uint16_t Servo_4;       // pulse width in micro seconds
  } INPUT_DATA;
}_SLAVE2_IN;

typedef union{
  byte B[14];
  struct{
      uint8_t GPIO_Status;  
      uint16_t AN_0;       
      uint16_t AN_1;       
      uint16_t AN_2;       
      uint16_t AN_3;
      uint32_t Sonar;     
  } OUTPUT_DATA;
}_SLAVE2_OUT;

#define GPIO_0_Mask B00000001
#define GPIO_1_Mask B00000010
#define GPIO_2_Mask B00000100
#define GPIO_3_Mask B00001000
#define GPIO_4_Mask B00010000
#define GPIO_5_Mask B00100000
#define GPIO_6_Mask B01000000

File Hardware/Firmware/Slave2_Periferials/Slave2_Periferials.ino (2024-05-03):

/*
    __  __ _             _        _    __   ___
   |  \/  (_)           (_)      //   /_ | / _ \
   | \  / |_ _ __   __ _ _ _ __ ___    | || | | |
   | |\/| | | '_ \ / _` | | '__/ _ \   | || | | |
   | |  | | | | | | (_| | | | | (_) |  | || |_| |
   |_|  |_|_|_| |_|\__,_|_|_|  \___/   |_(_)___/

   Descripción: Este firmware, realiza el control de los sistemas perifericos
   del Robot.

   Funciones del Slave2:
      - Control de 5 servos RC.
      - Control de 7 GPIO
      - Control de 4 AnalogInputs
      - Control del sonar por ultrasonidos.

   Versión: 1.0
   Autor: Daniel Flores Elias
   mail: daniel.flores@gmail.com

   Copyright (c) 2023 Institut Jaume Huguet-Valls, Daniel Flores
   <daniel.flores@gmail.com>  All rights reserved.
   See the bottom of this file for the license terms.

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
   1. Redistributions of source code must retain the above copyright
   notice, this list of conditions and the following disclaimer.

   2. Redistributions in binary form must reproduce the above copyright
   notice, this list of conditions and the following disclaimer in the
   documentation and/or other materials provided with the distribution.

   3. Neither the name of the copyright holder nor the names of its
   contributors may be used to endorse or promote products derived from
   this software without specific prior written permission.

   THIS SOFTWARE IS PROVIDED BY THE COPYRIGHT HOLDERS AND CONTRIBUTORS
   "AS IS" AND ANY EXPRESS OR IMPLIED WARRANTIES, INCLUDING, BUT NOT
   LIMITED TO, THE IMPLIED WARRANTIES OF MERCHANTABILITY AND FITNESS FOR
   A PARTICULAR PURPOSE ARE DISCLAIMED. IN NO EVENT SHALL THE COPYRIGHT
   HOLDER OR CONTRIBUTORS BE LIABLE FOR ANY DIRECT, INDIRECT, INCIDENTAL,
   SPECIAL, EXEMPLARY, OR CONSEQUENTIAL DAMAGES (INCLUDING, BUT NOT
   LIMITED TO, PROCUREMENT OF SUBSTITUTE GOODS OR SERVICES; LOSS OF USE,
   DATA, OR PROFITS; OR BUSINESS INTERRUPTION) HOWEVER CAUSED AND ON ANY
   THEORY OF LIABILITY, WHETHER IN CONTRACT, STRICT LIABILITY, OR TORT
   (INCLUDING NEGLIGENCE OR OTHERWISE) ARISING IN ANY WAY OUT OF THE USE
   OF THIS SOFTWARE, EVEN IF ADVISED OF THE POSSIBILITY OF SUCH DAMAGE.
*/

#include <EEPROM.h>
#include <Wire.h>
#include <Servo.h>
#include "COMParameters.h"

Servo SERVO_0, SERVO_1, SERVO_2, SERVO_3, SERVO_4;

int eeAddress = 0;
int SALVE_2_ADDR = 10;

_SLAVE2_IN  Slave_2_IN;
_SLAVE2_OUT Slave_2_OUT;
_SLAVE2_IN Slave_2_IN_copy;

unsigned long TempsOld = 0;
uint8_t tempsPulling = 20;

unsigned long TempsSonarOld = 0;
uint8_t tempsSonarPulling = 50;

int GPIO_0_pin = 7;
int GPIO_1_pin = 8;
int GPIO_2_pin = 11;
int GPIO_3_pin = 12;
int GPIO_4_pin = 13;
int GPIO_5_pin = 20;
int GPIO_6_pin = 21;
const int SONAR_TRIG_pin = 2;
const int SONAR_ECHO_pin = 4;
volatile uint32_t t, tH, tL;
volatile unsigned int pulseWidth = 0;
long duration;

int distance;
uint8_t TempByte = 0;
bool DataReceived = false;

void setup() {
  Wire.setClock( 400000L);
  Wire.begin(SALVE_2_ADDR);
  Wire.onRequest(RequestEven); // registrar evento de solicitud de datos
  Wire.onReceive(receiveEvent); // registrar evento de recepcion de datos
  Serial.begin(115200);
  SERVO_0.attach(3);
  SERVO_1.attach(5);
  SERVO_2.attach(6);
  SERVO_3.attach(9);
  SERVO_4.attach(10);
  Slave_2_IN.INPUT_DATA.Servo_0 = 1500;
  Slave_2_IN.INPUT_DATA.Servo_1 = 1500;
  Slave_2_IN.INPUT_DATA.Servo_2 = 1500;
  Slave_2_IN.INPUT_DATA.Servo_3 = 1500;
  Slave_2_IN.INPUT_DATA.Servo_4 = 1500;
  Slave_2_IN.INPUT_DATA.GPIO_Config = 0;
  Slave_2_IN.INPUT_DATA.GPIO_Value = 0;


  SERVO_0.writeMicroseconds(Slave_2_IN.INPUT_DATA.Servo_0);
  SERVO_1.writeMicroseconds(Slave_2_IN.INPUT_DATA.Servo_1);
  SERVO_2.writeMicroseconds(Slave_2_IN.INPUT_DATA.Servo_2);
  SERVO_3.writeMicroseconds(Slave_2_IN.INPUT_DATA.Servo_3);
  SERVO_4.writeMicroseconds(Slave_2_IN.INPUT_DATA.Servo_4);

  pinMode(SONAR_TRIG_pin, OUTPUT);
  pinMode(SONAR_ECHO_pin, INPUT);
  attachInterrupt(digitalPinToInterrupt(SONAR_ECHO_pin), ISR_Sonar, CHANGE);
}
//******************* Bucle principal *******************
void loop() {
  //////////// P U L L I N G //////////////
  if ( millis() - TempsSonarOld > tempsSonarPulling ) {
    TempsSonarOld = millis();

    //GENERAR PULSO DE SONAR
    Sonar_Pulse();
    //ACTUALIZAR DISTANCIA INDICADA POR EL SONAR
    //duration = pulseIn(SONAR_ECHO_pin, HIGH);
    // Calculating the distance
    //distance = int(duration * 0.034 / 2);
    Slave_2_OUT.OUTPUT_DATA.Sonar = pulseWidth;
    
    /*
    distance = pulseWidth*0.034/2;
    Slave_2_OUT.OUTPUT_DATA.Sonar = distance;
    pulseWidth = 0;
    */
  }

  
  if ( millis() - TempsOld > tempsPulling ) {
    TempsOld = millis();

    //REGISTRAR ESTADO DE LAS GPIOs:
    TempByte = digitalRead(GPIO_0_pin) ? TempByte | GPIO_0_Mask : TempByte & ~GPIO_0_Mask;
    TempByte = digitalRead(GPIO_1_pin) ? TempByte | GPIO_1_Mask : TempByte & ~GPIO_1_Mask;
    TempByte = digitalRead(GPIO_2_pin) ? TempByte | GPIO_2_Mask : TempByte & ~GPIO_2_Mask;
    TempByte = digitalRead(GPIO_3_pin) ? TempByte | GPIO_3_Mask : TempByte & ~GPIO_3_Mask;
    TempByte = digitalRead(GPIO_4_pin) ? TempByte | GPIO_4_Mask : TempByte & ~GPIO_4_Mask;
    TempByte = digitalRead(GPIO_5_pin) ? TempByte | GPIO_5_Mask : TempByte & ~GPIO_5_Mask;
    TempByte = digitalRead(GPIO_6_pin) ? TempByte | GPIO_6_Mask : TempByte & ~GPIO_6_Mask;

    Slave_2_OUT.OUTPUT_DATA.GPIO_Status = TempByte;


    //REGISTRAR ESTADO DE LAS ENTRADAS ANALÒGICAS:
    Slave_2_OUT.OUTPUT_DATA.AN_0 = analogRead(A0);
    Slave_2_OUT.OUTPUT_DATA.AN_1 = analogRead(A1);
    Slave_2_OUT.OUTPUT_DATA.AN_2 = analogRead(A2);
    Slave_2_OUT.OUTPUT_DATA.AN_3 = analogRead(A3);

  }///______________ FINAL DEL PULLING ______________

  ////////////   C O M U N I C A C I O N E S  ////////////
  if (DataReceived) {
    DataReceived = false; // Reinicia el valor de DataReceived
    bool GPIO_Config_Change = Slave_2_IN_copy.INPUT_DATA.GPIO_Config ^ Slave_2_IN.INPUT_DATA.GPIO_Config ? true : false ;
    bool GPIO_Value_Change = Slave_2_IN_copy.INPUT_DATA.GPIO_Value ^ Slave_2_IN.INPUT_DATA.GPIO_Value ? true : false ;
    bool Servo_0_Change = Slave_2_IN_copy.INPUT_DATA.Servo_0 ^ Slave_2_IN.INPUT_DATA.Servo_0 ? true : false ;
    bool Servo_1_Change = Slave_2_IN_copy.INPUT_DATA.Servo_1 ^ Slave_2_IN.INPUT_DATA.Servo_1 ? true : false ;
    bool Servo_2_Change = Slave_2_IN_copy.INPUT_DATA.Servo_2 ^ Slave_2_IN.INPUT_DATA.Servo_2 ? true : false ;
    bool Servo_3_Change = Slave_2_IN_copy.INPUT_DATA.Servo_3 ^ Slave_2_IN.INPUT_DATA.Servo_3 ? true : false ;
    bool Servo_4_Change = Slave_2_IN_copy.INPUT_DATA.Servo_4 ^ Slave_2_IN.INPUT_DATA.Servo_4 ? true : false ;
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

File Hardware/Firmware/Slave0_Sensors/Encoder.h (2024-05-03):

/* Encoder Library, for measuring quadrature encoded signals
 * http://www.pjrc.com/teensy/td_libs_Encoder.html
 * Copyright (c) 2011,2013 PJRC.COM, LLC - Paul Stoffregen <paul@pjrc.com>
 *
 * Version 1.2 - fix -2 bug in C-only code
 * Version 1.1 - expand to support boards with up to 60 interrupts
 * Version 1.0 - initial release
 * 
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
 * THE SOFTWARE IS PROVIDED "AS IS", WITHOUT WARRANTY OF ANY KIND, EXPRESS OR
 * IMPLIED, INCLUDING BUT NOT LIMITED TO THE WARRANTIES OF MERCHANTABILITY,
 * FITNESS FOR A PARTICULAR PURPOSE AND NONINFRINGEMENT. IN NO EVENT SHALL THE
 * AUTHORS OR COPYRIGHT HOLDERS BE LIABLE FOR ANY CLAIM, DAMAGES OR OTHER
 * LIABILITY, WHETHER IN AN ACTION OF CONTRACT, TORT OR OTHERWISE, ARISING FROM,
 * OUT OF OR IN CONNECTION WITH THE SOFTWARE OR THE USE OR OTHER DEALINGS IN
 * THE SOFTWARE.
 */


#ifndef Encoder_h_
#define Encoder_h_

#if defined(ARDUINO) && ARDUINO >= 100
#include <Arduino.h>
#elif defined(WIRING)
#include "Wiring.h"
#else
#include "WProgram.h"
#include "pins_arduino.h"
#endif

#include "utility/direct_pin_read.h"

#if defined(ENCODER_USE_INTERRUPTS) || !defined(ENCODER_DO_NOT_USE_INTERRUPTS)
#define ENCODER_USE_INTERRUPTS
#define ENCODER_ARGLIST_SIZE CORE_NUM_INTERRUPT
#include "utility/interrupt_pins.h"
#ifdef ENCODER_OPTIMIZE_INTERRUPTS
#include "utility/interrupt_config.h"
#endif
#else
#define ENCODER_ARGLIST_SIZE 0
#endif



// All the data needed by interrupts is consolidated into this ugly struct
// to facilitate assembly language optimizing of the speed critical update.
// The assembly code uses auto-incrementing addressing modes, so the struct
// must remain in exactly this order.
typedef struct {
	volatile IO_REG_TYPE * pin1_register;
	volatile IO_REG_TYPE * pin2_register;
	IO_REG_TYPE            pin1_bitmask;
	IO_REG_TYPE            pin2_bitmask;
	uint8_t                state;
	int32_t                position;
} Encoder_internal_state_t;

class Encoder
{
public:
	Encoder(uint8_t pin1, uint8_t pin2) {
		#ifdef INPUT_PULLUP
		pinMode(pin1, INPUT_PULLUP);
		pinMode(pin2, INPUT_PULLUP);
		#else
		pinMode(pin1, INPUT);
		digitalWrite(pin1, HIGH);
		pinMode(pin2, INPUT);
		digitalWrite(pin2, HIGH);
		#endif
		encoder.pin1_register = PIN_TO_BASEREG(pin1);
		encoder.pin1_bitmask = PIN_TO_BITMASK(pin1);
		encoder.pin2_register = PIN_TO_BASEREG(pin2);
		encoder.pin2_bitmask = PIN_TO_BITMASK(pin2);
		encoder.position = 0;
		// allow time for a passive R-C filter to charge
		// through the pullup resistors, before reading
		// the initial state
		delayMicroseconds(2000);
		uint8_t s = 0;
		if (DIRECT_PIN_READ(encoder.pin1_register, encoder.pin1_bitmask)) s |= 1;
		if (DIRECT_PIN_READ(encoder.pin2_register, encoder.pin2_bitmask)) s |= 2;
		encoder.state = s;
#ifdef ENCODER_USE_INTERRUPTS
		interrupts_in_use = attach_interrupt(pin1, &encoder);
		interrupts_in_use += attach_interrupt(pin2, &encoder);
#endif
		//update_finishup();  // to force linker to include the code (does not work)
	}


#ifdef ENCODER_USE_INTERRUPTS
	inline int32_t read() {
		if (interrupts_in_use < 2) {
			noInterrupts();
			update(&encoder);
		} else {
			noInterrupts();
		}
		int32_t ret = encoder.position;
		interrupts();
		return ret;
	}
	inline int32_t readAndReset() {
		if (interrupts_in_use < 2) {
			noInterrupts();
			update(&encoder);
		} else {
			noInterrupts();
		}
		int32_t ret = encoder.position;
		encoder.position = 0;
		interrupts();
		return ret;
	}
	inline void write(int32_t p) {
		noInterrupts();
		encoder.position = p;
		interrupts();
	}
#else
	inline int32_t read() {
		update(&encoder);
		return encoder.position;
	}
	inline int32_t readAndReset() {
		update(&encoder);
		int32_t ret = encoder.position;
		encoder.position = 0;
		return ret;
	}
	inline void write(int32_t p) {
		encoder.position = p;
	}
#endif
private:
	Encoder_internal_state_t encoder;
#ifdef ENCODER_USE_INTERRUPTS
	uint8_t interrupts_in_use;
#endif
public:
	static Encoder_internal_state_t * interruptArgs[ENCODER_ARGLIST_SIZE];

//                           _______         _______       
//               Pin1 ______|       |_______|       |______ Pin1
// negative <---         _______         _______         __      --> positive
//               Pin2 __|       |_______|       |_______|   Pin2

		//	new	new	old	old
		//	pin2	pin1	pin2	pin1	Result
		//	----	----	----	----	------
		//	0	0	0	0	no movement
		//	0	0	0	1	+1
		//	0	0	1	0	-1
		//	0	0	1	1	+2  (assume pin1 edges only)
		//	0	1	0	0	-1
		//	0	1	0	1	no movement
		//	0	1	1	0	-2  (assume pin1 edges only)
		//	0	1	1	1	+1
		//	1	0	0	0	+1
		//	1	0	0	1	-2  (assume pin1 edges only)
		//	1	0	1	0	no movement
		//	1	0	1	1	-1
		//	1	1	0	0	+2  (assume pin1 edges only)
		//	1	1	0	1	-1
		//	1	1	1	0	+1
		//	1	1	1	1	no movement
/*
	// Simple, easy-to-read "documentation" version :-)
	//
	void update(void) {
		uint8_t s = state & 3;
		if (digitalRead(pin1)) s |= 4;
		if (digitalRead(pin2)) s |= 8;
		switch (s) {
			case 0: case 5: case 10: case 15:
				break;
			case 1: case 7: case 8: case 14:
				position++; break;
			case 2: case 4: case 11: case 13:
				position--; break;
			case 3: case 12:
				position += 2; break;
			default:
				position -= 2; break;
		}
		state = (s >> 2);
	}
*/
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

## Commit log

2024-05-05 Resolved merge conflicts by merging unrelated histories
    [Minairo_TCP.py]
2024-05-14 se han añadido los STLs del Robot, y correcciones en el conexionado de sensores
    [BaseCorredera.STL, BaseRobot_BottomSide_V2.stl, BaseRoda80mm.stl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]
